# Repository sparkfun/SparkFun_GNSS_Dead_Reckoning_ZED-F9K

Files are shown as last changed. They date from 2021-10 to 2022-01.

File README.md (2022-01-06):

SparkFun GNSS-RTK Dead Reckoning Breakout - ZED-F9K (Qwiic)
========================================

SparkFun GNSS-RTK Dead Reckoning Breakout - ZED-F9K (Qwiic) (https://www.sparkfun.com/products/18719)

[*SparkFun GNSS-RTK Dead Reckoning Breakout - ZED-F9K (Qwiic) (GPS-18719)*](https://www.sparkfun.com/products/18719)

The SparkFun ZED-F9K GNSS Breakout is a high precision, sensor fusion geospatial board with equally impressive configuration options and takes advantage of u-blox's Automotive Dead Reckoning (ADR) technology. The ZED-F9K module provides a highly accurate and continuous position by fusing a 3D IMU sensor, wheel ticks, a vehicle dynamics model, correction data, and GNSS measurements. 

The ZED-F9K module is a 184-channel u-blox F9 engine GNSS receiver, meaning it can receive signals from the GPS, GLONASS, Galileo, and BeiDou constellations with ~0.2 meter accuracy! That's right, such accuracy can be achieved with an  RTK navigation solution when used with a correction source. Note that the ZED-F9K can only operate as a rover, so you will need to connect to a base station. The module supports concurrent reception of four GNSS systems. The combination of GNSS and integrated 3D sensor measurements on the ZED-F9K provide accurate, real-time positioning rates of up to 30Hz.

Compared to other GPS modules, this breakout maximizes position accuracy in dense cities or covered areas. Even under poor signal conditions, continuous positioning is provided in urban environments and is also available during complete signal loss (e.g. short tunnels and parking garages). The ZED-F9K is the ultimate solution for autonomous robotic applications that require accurate positioning under challenging conditions.

Additionally, this u-blox receiver supports I<sup>2</sup>C (u-blox calls this Display Data Channel) which makes it perfect for the Qwiic compatibility so we don't have to use up our precious UART ports. Utilizing our handy Qwiic system, no soldering is required to connect it to the rest of your system. However, we still have broken out 0.1"-spaced pins in case you prefer to use a breadboard.

The SparkFun ZED-F9K GPS Breakout is also equipped with an on-board rechargeable battery that provides power to the RTC on the ZED-F9K.  This reduces the time-to-first fix from a cold start (~26s) to a hot start (~2s). The battery will maintain RTC and GNSS orbit data without being connected to power for plenty of time. The breakout board has five communications ports, four of which are all active simultaneously: USB-C (which enumerates as a COM port), UART1 (with 3.3V TTL), UART2 for RTCM reception (with 3.3V TTL), I<sup>2</sup>C (via the one Qwiic connnector or broken out pins), and SPI. One SMA connector is included for a secure connection to an antenna.

U-blox based GPS products are configurable using the popular, but dense, Windows program called u-center. Plenty of different functions can be configured on the ZED-F9K: baud rates, update rates, geofencing, spoofing detection, external interrupts, SBAS/D-GPS, etc. All of this can be done within the [SparkFun Arduino Library](https://github.com/sparkfun/SparkFun_u-blox_GNSS_Arduino_Library)!

Repository Contents
-------------------

* **/Hardware** - Eagle design files (.brd, .sch)
* **/Production** - Production panel files (.brd)

Documentation
--------------
* **[Library](https://github.com/sparkfun/SparkFun_u-blox_GNSS_Arduino_Library)** - Arduino library
* **[Hookup Guide](https://learn.sparkfun.com/tutorials/2005)** - Basic hookup guide

Product Versions
----------------
* [GPS-18719](https://www.sparkfun.com/products/18719) - Initial release

Version History
---------------
* v1.0 - Initial Release 

License Information
-------------------

This product is _**open source**_! 

Please review the LICENSE.md file for license information. 

If you have any questions or concerns on licensing, please contact technical support on our [SparkFun forums](https://forum.sparkfun.com/viewforum.php?f=152).

Distributed as-is; no warranty is given.

- Your friends at SparkFun.

_<COLLABORATION CREDIT>_

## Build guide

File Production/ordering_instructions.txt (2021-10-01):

panel size, 101x186mm
PCB thickness, 1.6mm
number of layers, 2
soldermask color, Red
silkscreen color, White
oz copper, 1oz
finish, HASL lead free
stencils, top
pcs per panel, 6
min trace width, 0.2540mm / 0.0100in
min drill size, 0.3048mm / 0.0120in

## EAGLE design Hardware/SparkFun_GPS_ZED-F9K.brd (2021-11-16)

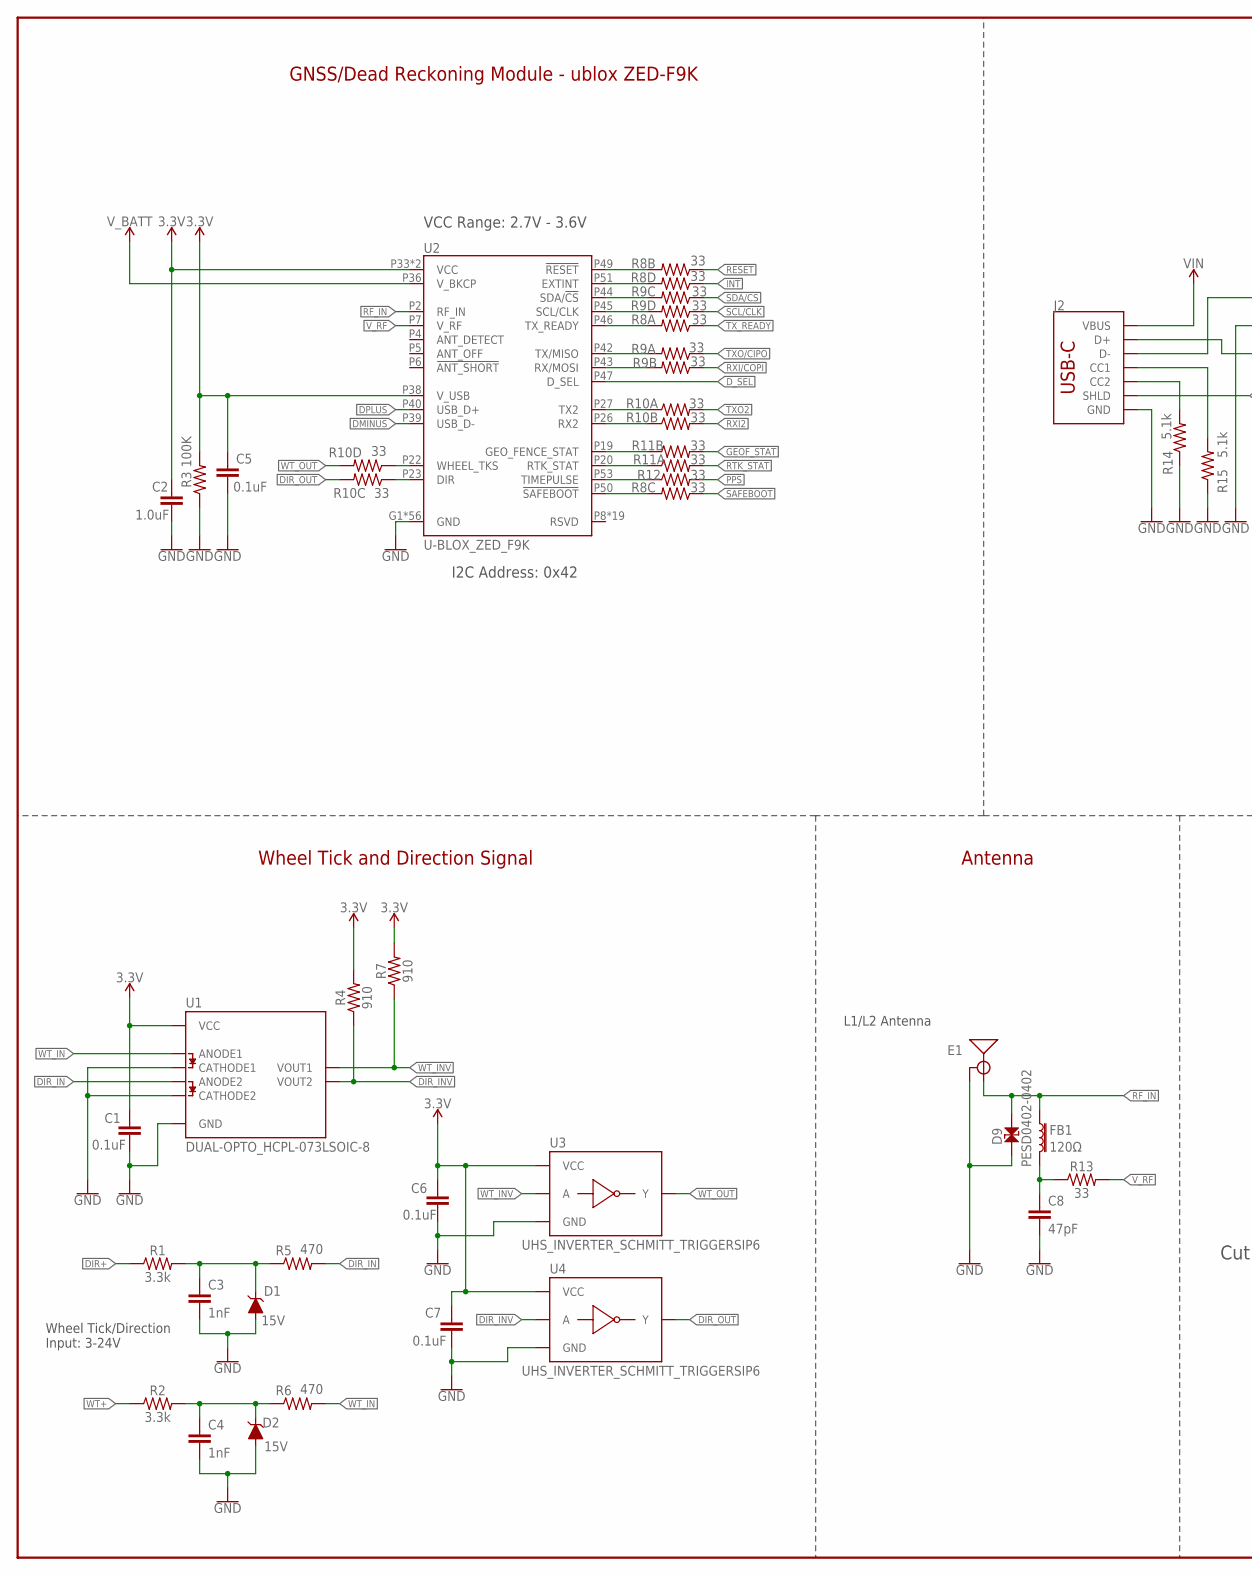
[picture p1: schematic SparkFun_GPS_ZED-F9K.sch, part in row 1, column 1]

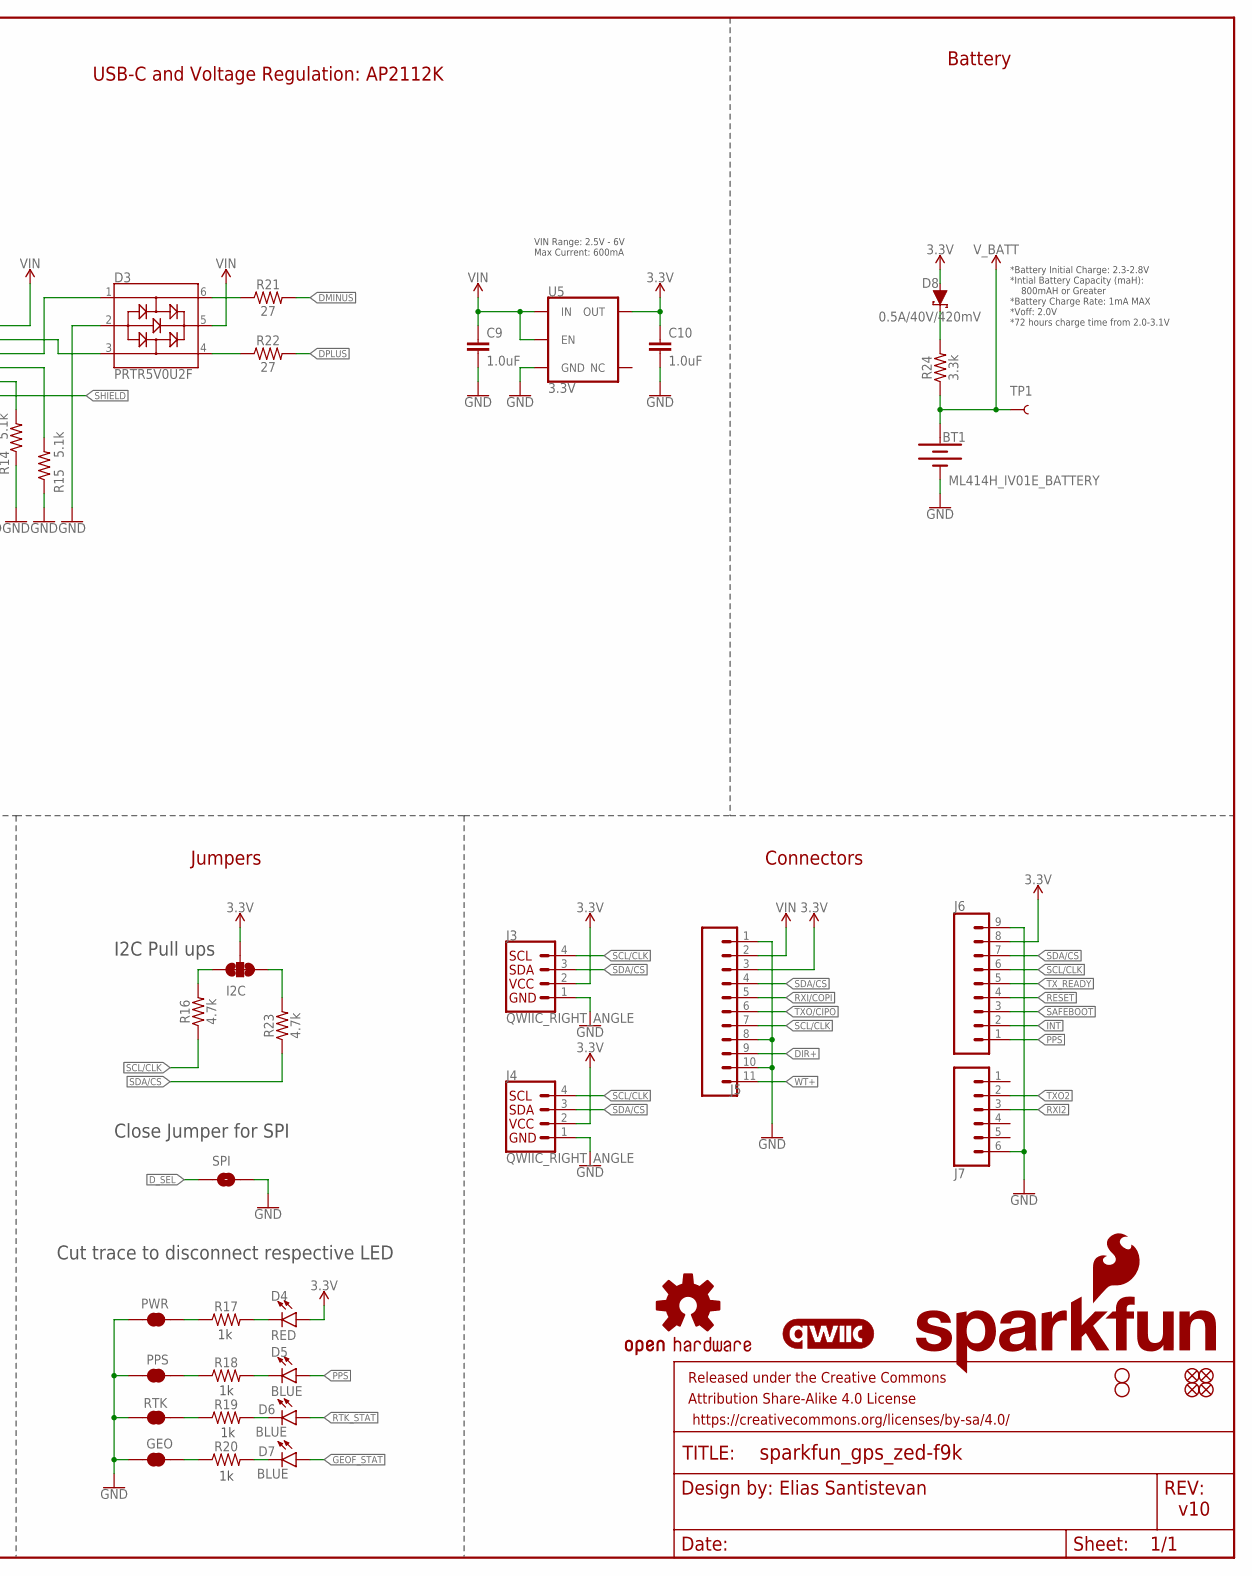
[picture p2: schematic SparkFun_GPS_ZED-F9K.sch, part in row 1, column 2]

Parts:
$1_25_$_2020-03-30_22-52-05: STAND-OFFTIGHT; STAND-OFF-TIGHT
BT1: ML414H_IV01E_BATTERY; ML414H_IV01E
C1, C5, C6, C7: 0.1uF; 0402-TIGHT
C2, C9, C10: 1.0uF; 0402-TIGHT
C3, C4: 1nF; 0402
C8: 47pF; 0402
D1, D2: 15V; SOT23-3
D3: PRTR5V0U2F; SOT886
D4: RED; LED-0603
D5, D6, D7: BLUE; LED-0603
D8: 0.5A/40V/420mV; SOD-323
D9: PESD0402-0402; 0402
E1: ANTENNA-SMA-GROUNDEDEDGE_SMA; SMA-EDGE
FB1: 120Ω; 0402
FD1, FD2, FD3, FD4: FIDUCIALUFIDUCIAL; FIDUCIAL-MICRO
FRAME1: FRAME-LEDGER; CREATIVE_COMMONS
GEO: JUMPER-SMT_2_NC_TRACE_SILK; SMT-JUMPER_2_NC_TRACE_SILK
H2: STAND-OFFTIGHT; STAND-OFF-TIGHT
I2C: JUMPER-SMT_3_2-NC_TRACE_SILK; SMT-JUMPER_3_2-NC_TRACE_SILK
J2: USB_C_2-LAYER_PADS; USB-C-16P-2LAYER-PADS
J3, J4: QWIIC_RIGHT_ANGLE; JST04_1MM_RA
J5: CONN_111X11_NO_SILK; 1X11_NO_SILK
J6: CONN_09NO_SILK; 1X09_NO_SILK
J7: CONN_06NO_SILK_NO_POP; 1X06_NO_SILK
LOGO1: OSHW-LOGOS; OSHW-LOGO-S
LOGO2: QWIIC_LOGO_4MM; QWIIC_4MM
LOGO3: SFE_LOGO_NAME_FLAME.2_INCH; SFE_LOGO_NAME_FLAME_.2
PPS: JUMPER-SMT_2_NC_TRACE_SILK; SMT-JUMPER_2_NC_TRACE_SILK
PWR: JUMPER-SMT_2_NC_TRACE_SILK; SMT-JUMPER_2_NC_TRACE_SILK
R1, R2, R24: 3.3k; 0603
R3: 100K; 0402
R4, R7: 910; 0603
R5, R6: 470; 0603
R8, R9, R10, R11: 33; 1206_RA
R12, R13: 33; 0603
R14, R15: 5.1k; 0402
R16, R23: 4.7k; 0402-TIGHT
R17, R18, R19, R20: 1KOHM-0402-1/16W-1%; 0402
R21, R22: 27; 0603
RTK: JUMPER-SMT_2_NC_TRACE_SILK; SMT-JUMPER_2_NC_TRACE_SILK
SPI: JUMPER-SMT_2_NO_SILK; SMT-JUMPER_2_NO_SILK
TP1: TEST-POINT3X5; PAD.03X.05
U1: DUAL-OPTO_HCPL-073LSOIC-8; SO08
U2: U-BLOX_ZED_F9K; UBLOX_ZED_F9K
U3, U4: UHS_INVERTER_SCHMITT_TRIGGERSIP6; SIP6
U5: 3.3V; SOT23-5

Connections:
3.3V: C1.1, C2.1, C5.1, C6.1, C7.1, C10.1, D4.A, D8.A, I2C.2, J3.2, J4.2, J5.3, J6.8, R3.2, R4.2, R7.2, U1.8 (VCC), U2.P33 (VCC), U2.P34 (VCC), U2.P38 (V_USB), U3.P6 (VCC), U4.P6 (VCC), U5.5 (OUT)
!RESET: J6.4, R8.P2 (1)
!SAFEBOOT: J6.3, R8.P3 (1)
DIR+: J5.9, R1.1
DIR_IN: R5.2, U1.4 (ANODE2)
DIR_INV: R4.1, U1.6 (VOUT2), U4.P2 (A)
DIR_OUT: R10.P6 (2), U4.P4 (Y)
DMINUS: R21.2, U2.P39 (USB_D-)
DPLUS: R22.2, U2.P40 (USB_D+)
D_SEL: SPI.1, U2.P47 (D_SEL)
GEOF_STAT: D7.A, R11.P7 (2)
GND: BT1.-, C1.2, C2.2, C3.2, C4.2, C5.2, C6.2, C7.2, C8.2, C9.2, C10.2, D1.1 (A), D2.1 (A), D3.2, D9.1, E1.GND@0 (GND), E1.GND@1 (GND), E1.GND@2 (GND), E1.GND@3 (GND), GEO.1, J2.GND, J2.GND2 (GND), J3.1, J4.1, J5.1, J5.8, J5.10, J6.9, J7.6, PPS.1, PWR.1, R3.1, R14.1, R15.1, RTK.1, SPI.2, U1.2 (CATHODE1), U1.3 (CATHODE2), U1.5 (GND), U2.G1 (GND), U2.G2 (GND), U2.G3 (GND), U2.G4 (GND), U2.G5 (GND), U2.G6 (GND), U2.G7 (GND), U2.G8 (GND), U2.G9 (GND), U2.G10 (GND), U2.G11 (GND), U2.G12 (GND), U2.G13 (GND), U2.G14 (GND), U2.G15 (GND), U2.G16 (GND), U2.G17 (GND), U2.G18 (GND), U2.G19 (GND), U2.G20 (GND), U2.G21 (GND), U2.G22 (GND), U2.G23 (GND), U2.G24 (GND), U2.G25 (GND), U2.G26 (GND), U2.G27 (GND), U2.G28 (GND), U2.G29 (GND), U2.G30 (GND), U2.G31 (GND), U2.G32 (GND), U2.G33 (GND), U2.G34 (GND), U2.G35 (GND), U2.G36 (GND), U2.G37 (GND), U2.G38 (GND), U2.G39 (GND), U2.G40 (GND), U2.G41 (GND), U2.G42 (GND), U2.G43 (GND), U2.G44 (GND), U2.G45 (GND), U2.G46 (GND), U2.G47 (GND), U2.G48 (GND), U2.P1 (GND), U2.P3 (GND), U2.P12 (GND), U2.P14 (GND), U2.P32 (GND), U2.P37 (GND), U2.P41 (GND), U2.P48 (GND), U3.P3 (GND), U4.P3 (GND), U5.2 (GND)
INT: J6.2, R8.P4 (1)
unnamed: I2C.1, R23.2
unnamed: D8.C, R24.2
unnamed: I2C.3, R16.2
unnamed: D4.C, R17.2
unnamed: C8.1, FB1.2, R13.1
unnamed: D3.3, J2.A6 (D+), J2.B6 (D+)
unnamed: D3.1, J2.A7 (D-), J2.B7 (D-)
unnamed: PWR.2, R17.1
unnamed: D3.6, R21.1
unnamed: D3.4, R22.1
unnamed: R8.P7 (2), U2.P49 (!RESET!)
unnamed: R8.P5 (2), U2.P51 (EXTINT)
unnamed: J2.B5 (CC2), R14.2
unnamed: J2.A5 (CC1), R15.2
unnamed: R9.P6 (2), U2.P44 (SDA/!CS!)
unnamed: R9.P5 (2), U2.P45 (SCL/CLK)
unnamed: R8.P8 (2), U2.P46 (TX_READY)
unnamed: R9.P8 (2), U2.P42 (TX/MISO)
unnamed: R9.P7 (2), U2.P43 (RX/MOSI)
unnamed: R10.P1 (1), U2.P27 (TX2)
unnamed: R19.1, RTK.2
unnamed: PPS.2, R18.1
unnamed: D5.C, R18.2
unnamed: D6.C, R19.2
unnamed: R10.P2 (1), U2.P26 (RX2)
unnamed: R11.P2 (1), U2.P19 (GEO_FENCE_STAT)
unnamed: R11.P1 (1), U2.P20 (RTK_STAT)
unnamed: R12.1, U2.P53 (TIMEPULSE)
unnamed: R8.P6 (2), U2.P50 (!SAFEBOOT!)
unnamed: R10.P4 (1), U2.P22 (WHEEL_TKS)
unnamed: R10.P3 (1), U2.P23 (DIR)
unnamed: GEO.2, R20.1
unnamed: D7.C, R20.2
unnamed: C4.1, D2.3 (C), R2.2, R6.1
unnamed: C3.1, D1.3 (C), R1.2, R5.1
PPS: D5.A, J6.1, R12.2
RF_IN: D9.2, E1.SIG (SIGNAL), FB1.1, U2.P2 (RF_IN)
RTK_STAT: D6.A, R11.P8 (2)
RXI2: J7.3, R10.P7 (2)
RXI/COPI: J5.5, R9.P2 (1)
SCL/CLK: J3.4, J4.4, J5.7, J6.6, R9.P4 (1), R16.1
SDA/!CS: J3.3, J4.3, J5.4, J6.7, R9.P3 (1), R23.1
SHIELD: J2.SHLD1 (SHLD), J2.SHLD2 (SHLD), J2.SHLD3 (SHLD), J2.SHLD4 (SHLD)
TXO2: J7.2, R10.P8 (2)
TXO/CIPO: J5.6, R9.P1 (1)
TX_READY: J6.5, R8.P1 (1)
VIN: C9.1, D3.5, J2.VBUS1 (VBUS), J2.VBUS2 (VBUS), J5.2, U5.1 (IN), U5.3 (EN)
V_BATT: BT1.+, R24.1, TP1.1, U2.P36 (V_BKCP)
V_RF: R13.2, U2.P7 (V_RF)
WT+: J5.11, R2.1
WT_IN: R6.2, U1.1 (ANODE1)
WT_INV: R7.1, U1.7 (VOUT1), U3.P2 (A)
WT_OUT: R10.P5 (2), U3.P4 (Y)

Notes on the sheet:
v10
Elias Santistevan
GNSS/Dead Reckoning Module - ublox ZED-F9K
Battery
Connectors
Jumpers
Close Jumper for SPI
I2C Pull ups
Cut trace to disconnect respective LED
Antenna
*Battery Initial Charge: 2.3-2.8V *Intial Battery Capacity (maH): 800mAH or Greater *Battery Charge Rate: 1mA MAX *Voff: 2.0V *72 hours charge time from 2.0-3.1V
VIN Range: 2.5V - 6V Max Current: 600mA
USB-C and Voltage Regulation: AP2112K
VCC Range: 2.7V - 3.6V
I2C Address: 0x42
Wheel Tick and Direction Signal
Wheel Tick/Direction Input: 3-24V
L1/L2 Antenna

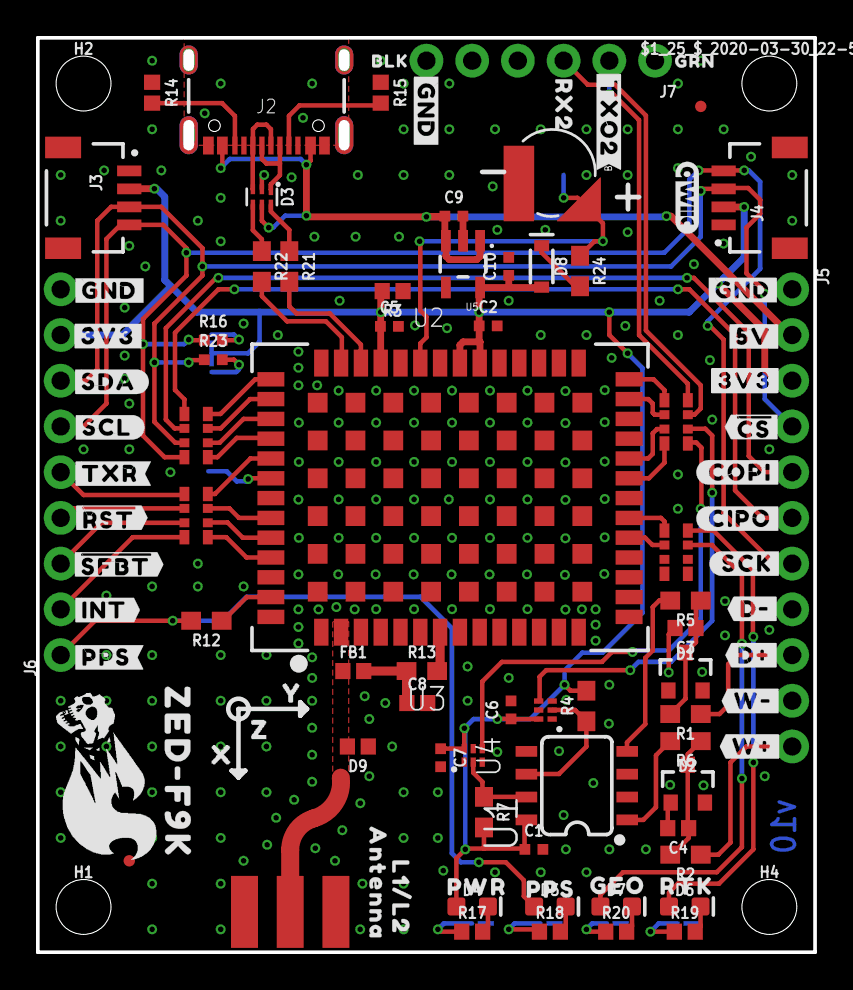
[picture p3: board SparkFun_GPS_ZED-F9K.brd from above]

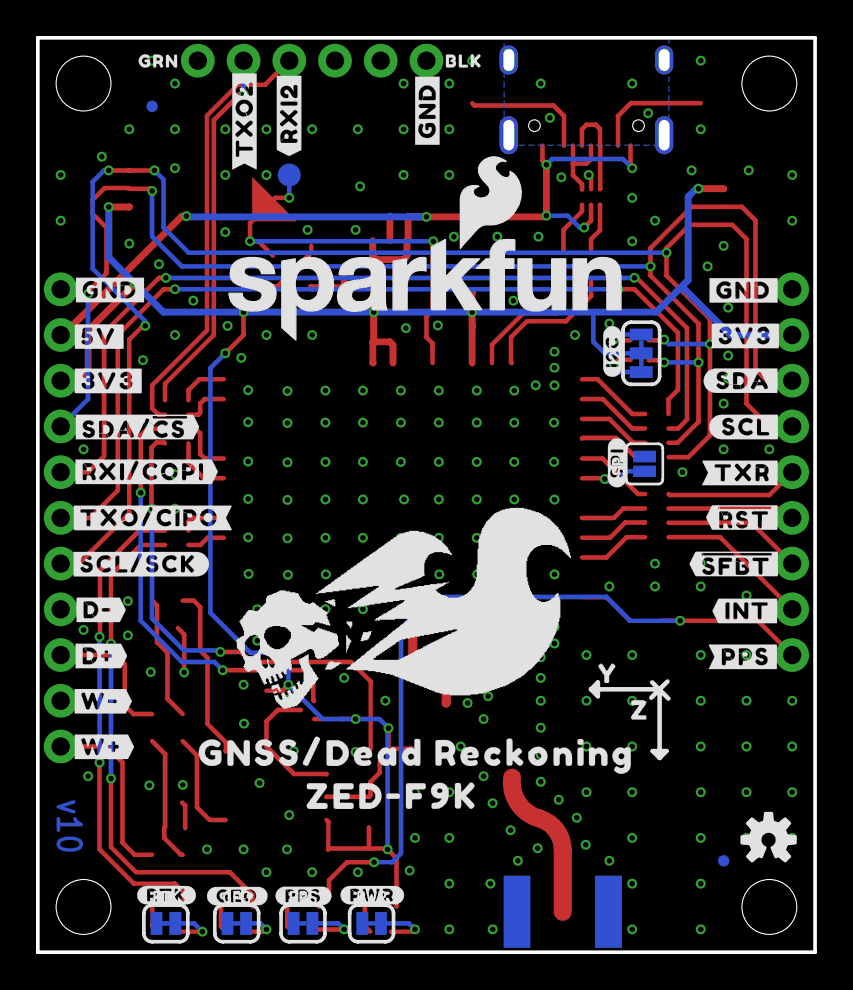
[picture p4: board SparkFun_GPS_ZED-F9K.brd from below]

Board: 2 copper layers, 43.2 x 50.8 mm, 149 parts (47 on the bottom side), 66 nets.

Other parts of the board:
H1, H4: STAND-OFFTIGHT; STAND-OFF-TIGHT
U$1: PWR22
U$2: PPS21
U$3: GEO23
U$4: RTK24
U$5: #W##16
U$6: #W##15
U$7, U$14, U$22, U$37, U$55: #3V3#6
U$8: #D##13
U$9: #D##14
U$10: #SCK#12
U$11: #CIPO#10
U$12: #COPI#9
U$13: ##CS##11
U$15, U$24: #5V#1
U$16, U$17, U$25, U$36, U$44, U$58: #GND#0
U$18: #TXO2#20
U$19, U$20: DEAD#RECKONING#GPS#BOARD#SILK#FINAL#JPG
U$21: RX224
U$23: BLK225
U$26: GRN226
U$27: #SDA##CS##10
U$28: #RXI#COPI#8
U$30: #SCL#SCK#12
U$31: #D##6
U$32: X1
U$33: #D##7
U$34: #W##4
U$35: #W##5
U$38: #SDA#6
U$39: #SCL#7
U$40: #TXR#3
U$41: ##RST##16
U$42: ##SFBT##17
U$43: #INT#8
U$45: #PPS#0
U$46: #RTK#25
U$47: #GEO#24
U$48: #PPS#21
U$49: L1#L2229
U$50, U$52: Y2
U$51: #PWR#23
U$53: #SPI#22
U$54: #I2C#23
U$56: #SDA#12
U$57, U$63: Z0
U$59: #RXI2#227
U$60: #TXO2#1
U$61: BLK227
U$62: ANTENNA229
U$64: GRN228
U$65: GNSS#DEAD_RECKONING230
U$66: #SCL#13
U$67: #TXR#19
U$68: ##RST##17
U$69: ##SFBT##18
U$70: #INT#14
U$71: #PPS#20
U$72, U$73: ZED#F9K230
U$74: #TXO#CIPO#9

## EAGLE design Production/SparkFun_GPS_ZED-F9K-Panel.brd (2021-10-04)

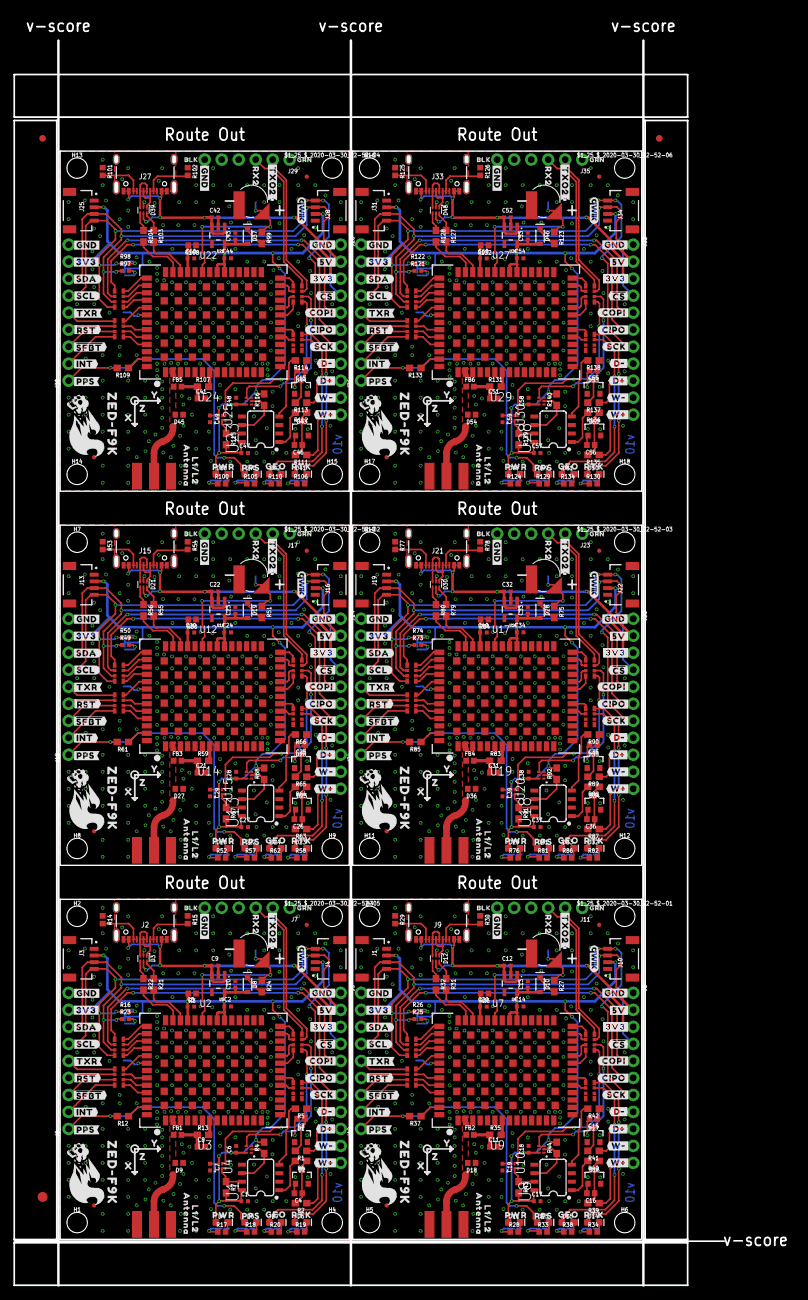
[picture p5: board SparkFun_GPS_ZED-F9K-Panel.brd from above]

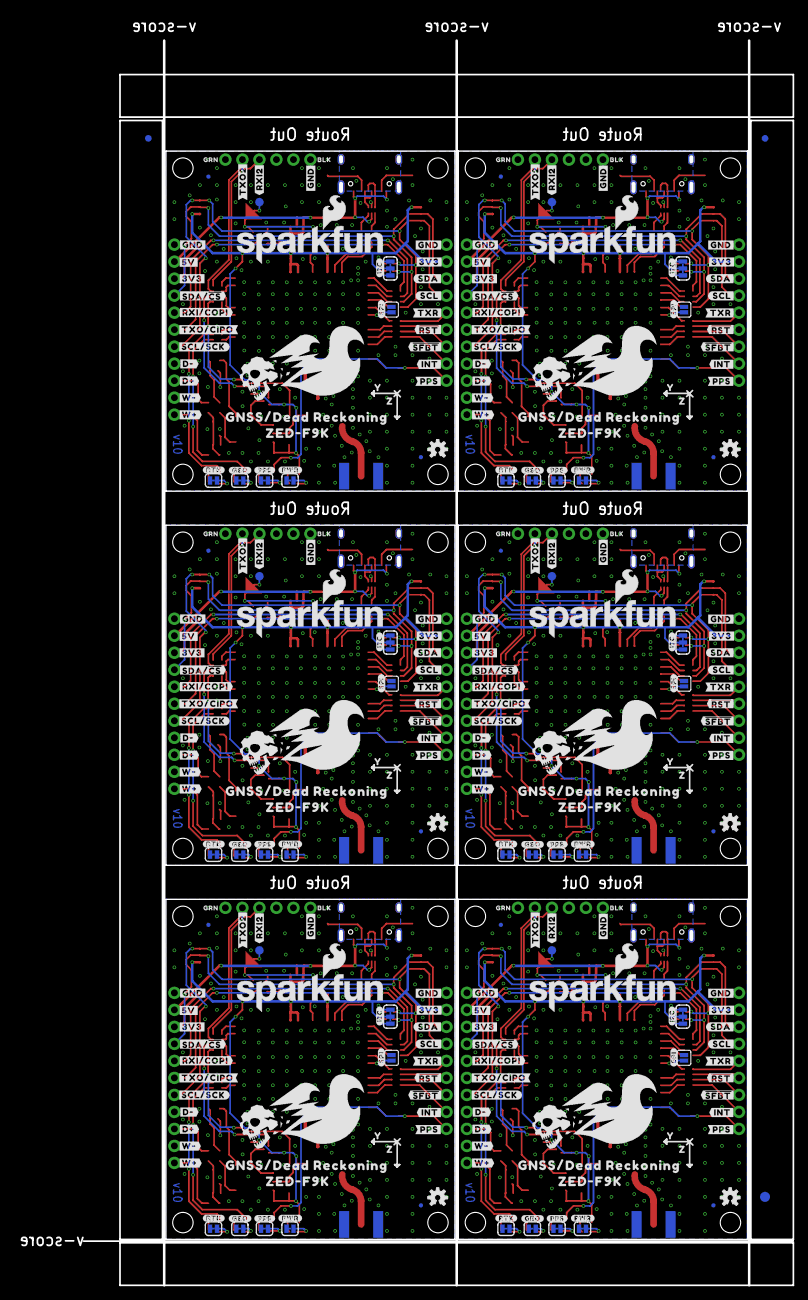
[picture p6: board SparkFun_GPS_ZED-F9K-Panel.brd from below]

Board: 2 copper layers, 106.0 x 185.9 mm, 894 parts (285 on the bottom side), 396 nets.

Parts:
$1_25_$_2020-03-30_22-52-01, $1_25_$_2020-03-30_22-52-02, $1_25_$_2020-03-30_22-52-03, $1_25_$_2020-03-30_22-52-04, $1_25_$_2020-03-30_22-52-05, $1_25_$_2020-03-30_22-52-06: STAND-OFFTIGHT; STAND-OFF-TIGHT
BT1, BT2, BT3, BT4, BT5, BT6: ML414H_IV01E_BATTERY; ML414H_IV01E
C1, C5, C6, C7, C17, C18, C19, C20, C27, C28, C29, C30, C37, C38, C39, C40, C47, C48, C49, C50, C57, C58, C59, C60: 0.1uF; 0402-TIGHT
C2, C9, C10, C12, C13, C14, C22, C23, C24, C32, C33, C34, C42, C43, C44, C52, C53, C54: 1.0uF; 0402-TIGHT
C3, C4, C15, C16, C25, C26, C35, C36, C45, C46, C55, C56: 1nF; 0402
C8, C11, C21, C31, C41, C51: 47pF; 0402
D1, D2, D16, D17, D25, D26, D34, D35, D43, D44, D52, D53: 15V; SOT23-3
D3, D12, D21, D30, D39, D48: PRTR5V0U2F; SOT886
D4, D11, D20, D29, D38, D47: RED; LED-0603
D5, D6, D7, D13, D14, D15, D22, D23, D24, D31, D32, D33, D40, D41, D42, D49, D50, D51: BLUE; LED-0603
D8, D10, D19, D28, D37, D46: 0.5A/40V/420mV; SOD-323
D9, D18, D27, D36, D45, D54: PESD0402; 0402
E1, E2, E3, E4, E5, E6: ANTENNA-SMA-GROUNDEDEDGE_SMA; SMA-EDGE
E$1, E$2, E$3, E$4: FIDUCIAL-1X2
E$5, E$6: FIDUCIAL-1.5X3
FB1, FB2, FB3, FB4, FB5, FB6: 120Ω; 0402
FD1, FD2, FD3, FD4, FD5, FD6, FD7, FD8, FD9, FD10, FD11, FD12, FD13, FD14, FD15, FD16, FD17, FD18, FD19, FD20, FD21, FD22, FD23, FD24: FIDUCIALUFIDUCIAL; FIDUCIAL-MICRO
GEO, GEO1, GEO2, GEO3, GEO4, GEO5: JUMPER-SMT_2_NC_TRACE_SILK; SMT-JUMPER_2_NC_TRACE_SILK
H1, H2, H3, H4, H5, H6, H7, H8, H9, H10, H11, H12, H13, H14, H15, H16, H17, H18: STAND-OFFTIGHT; STAND-OFF-TIGHT
I2C, I2C1, I2C2, I2C3, I2C4, I2C5: JUMPER-SMT_3_2-NC_TRACE_SILK; SMT-JUMPER_3_2-NC_TRACE_SILK
J1, J3, J4, J10, J13, J16, J19, J22, J25, J28, J31, J34: QWIIC_RIGHT_ANGLE; JST04_1MM_RA
J2, J9, J15, J21, J27, J33: USB-C-16P-2LAYER-PADS
J5, J8, J14, J20, J26, J32: 1X11_NO_SILK
J6, J12, J18, J24, J30, J36: 1X09_NO_SILK
J7, J11, J17, J23, J29, J35: 1X06_NO_SILK
LOGO1, LOGO6, LOGO9, LOGO12, LOGO15, LOGO18: OSHW-LOGOS; OSHW-LOGO-S
LOGO2, LOGO5, LOGO8, LOGO11, LOGO14, LOGO17: QWIIC_LOGO_4MM; QWIIC_4MM
LOGO3, LOGO4, LOGO7, LOGO10, LOGO13, LOGO16: SFE_LOGO_NAME_FLAME.2_INCH; SFE_LOGO_NAME_FLAME_.2
PPS, PPS1, PPS2, PPS3, PPS4, PPS5: JUMPER-SMT_2_NC_TRACE_SILK; SMT-JUMPER_2_NC_TRACE_SILK
PWR, PWR1, PWR2, PWR3, PWR4, PWR5: JUMPER-SMT_2_NC_TRACE_SILK; SMT-JUMPER_2_NC_TRACE_SILK
R1, R2, R24, R27, R39, R41, R51, R63, R65, R75, R87, R89, R99, R111, R113, R123, R135, R137: 3.3k; 0603
R3, R36, R60, R84, R108, R132: 100K; 0402
R4, R7, R43, R44, R67, R68, R91, R92, R115, R116, R139, R140: 910; 0603
R5, R6, R40, R42, R64, R66, R88, R90, R112, R114, R136, R138: 470; 0603
R8, R9, R10, R11, R45, R46, R47, R48, R69, R70, R71, R72, R93, R94, R95, R96, R117, R118, R119, R120, R141, R142, R143, R144: 33; 1206_RA
R12, R13, R35, R37, R59, R61, R83, R85, R107, R109, R131, R133: 33; 0603
R14, R15, R29, R30, R53, R54, R77, R78, R101, R102, R125, R126: 5.1k; 0402
R16, R23, R25, R26, R49, R50, R73, R74, R97, R98, R121, R122: 4.7k; 0402-TIGHT
R17, R18, R19, R20, R28, R33, R34, R38, R52, R57, R58, R62, R76, R81, R82, R86, R100, R105, R106, R110, R124, R129, R130, R134: 1KOHM-0402-1/16W-1%; 0402
R21, R22, R31, R32, R55, R56, R79, R80, R103, R104, R127, R128: 27; 0603
RTK, RTK1, RTK2, RTK3, RTK4, RTK5: JUMPER-SMT_2_NC_TRACE_SILK; SMT-JUMPER_2_NC_TRACE_SILK
SPI, SPI1, SPI2, SPI3, SPI4, SPI5: JUMPER-SMT_2_NO_SILK; SMT-JUMPER_2_NO_SILK
TP1, TP2, TP3, TP4, TP5, TP6: TEST-POINT3X5; PAD.03X.05
U1, U8, U13, U18, U23, U28: DUAL-OPTO_HCPL-073LSOIC-8; SO08
U2, U7, U12, U17, U22, U27: U-BLOX_ZED_F9K; UBLOX_ZED_F9K
U3, U4, U9, U10, U14, U15, U19, U20, U24, U25, U29, U30: UHS_INVERTER_SCHMITT_TRIGGERSIP6; SIP6
U5, U6, U11, U16, U21, U26: 3.3V; SOT23-5
U$1, U$81, U$154, U$227, U$300, U$373: PWR22
U$2, U$82, U$155, U$228, U$301, U$374: PPS21
U$3, U$83, U$156, U$229, U$302, U$375: GEO23
U$4, U$84, U$157, U$230, U$303, U$376: RTK24
U$5, U$85, U$158, U$231, U$304, U$377: #W##16
U$6, U$86, U$159, U$232, U$305, U$378: #W##15
U$7, U$14, U$22, U$37, U$55, U$92, U$101, U$109, U$110, U$121, U$165, U$174, U$182, U$183, U$194, U$238, U$247, U$255, U$256, U$267, U$311, U$320, U$328, U$329, U$340, U$384, U$393, U$401, U$402, U$413: #3V3#6
U$8, U$87, U$160, U$233, U$306, U$379: #D##13
U$9, U$88, U$161, U$234, U$307, U$380: #D##14
U$10, U$89, U$162, U$235, U$308, U$381: #SCK#12
U$11, U$90, U$163, U$236, U$309, U$382: #CIPO#10
U$12, U$91, U$164, U$237, U$310, U$383: #COPI#9
U$13, U$108, U$181, U$254, U$327, U$400: ##CS##11
U$15, U$24, U$93, U$111, U$166, U$184, U$239, U$257, U$312, U$330, U$385, U$403: #5V#1
U$16, U$17, U$25, U$36, U$44, U$58, U$94, U$95, U$100, U$112, U$120, U$137, U$167, U$168, U$173, U$185, U$193, U$210, U$240, U$241, U$246, U$258, U$266, U$283, U$313, U$314, U$319, U$331, U$339, U$356, U$386, U$387, U$392, U$404, U$412, U$429: #GND#0
U$18, U$96, U$169, U$242, U$315, U$388: #TXO2#20
U$19, U$20, U$29, U$75, U$147, U$148, U$220, U$221, U$293, U$294, U$366, U$367: DEAD#RECKONING#GPS#BOARD#SILK#FINAL#JPG
U$21, U$97, U$170, U$243, U$316, U$389: RX224
U$23, U$98, U$171, U$244, U$317, U$390: BLK225
U$26, U$99, U$172, U$245, U$318, U$391: GRN226
U$27, U$113, U$186, U$259, U$332, U$405: #SDA##CS##10
U$28, U$114, U$187, U$260, U$333, U$406: #RXI#COPI#8
U$30, U$115, U$188, U$261, U$334, U$407: #SCL#SCK#12
U$31, U$116, U$189, U$262, U$335, U$408: #D##6
U$32, U$76, U$149, U$222, U$295, U$368: X1
U$33, U$117, U$190, U$263, U$336, U$409: #D##7
U$34, U$118, U$191, U$264, U$337, U$410: #W##4
U$35, U$119, U$192, U$265, U$338, U$411: #W##5
U$38, U$122, U$195, U$268, U$341, U$414: #SDA#6
U$39, U$123, U$196, U$269, U$342, U$415: #SCL#7
U$40, U$124, U$197, U$270, U$343, U$416: #TXR#3
U$41, U$125, U$198, U$271, U$344, U$417: ##RST##16
U$42, U$126, U$199, U$272, U$345, U$418: ##SFBT##17
U$43, U$127, U$200, U$273, U$346, U$419: #INT#8
U$45, U$128, U$201, U$274, U$347, U$420: #PPS#0
U$46, U$129, U$202, U$275, U$348, U$421: #RTK#25
U$47, U$130, U$203, U$276, U$349, U$422: #GEO#24
U$48, U$131, U$204, U$277, U$350, U$423: #PPS#21
U$49, U$142, U$215, U$288, U$361, U$434: L1#L2229
U$50, U$52, U$77, U$78, U$150, U$151, U$223, U$224, U$296, U$297, U$369, U$370: Y2
U$51, U$132, U$205, U$278, U$351, U$424: #PWR#23
U$53, U$133, U$206, U$279, U$352, U$425: #SPI#22
U$54, U$134, U$207, U$280, U$353, U$426: #I2C#23
U$56, U$102, U$175, U$248, U$321, U$394: #SDA#12
U$57, U$63, U$79, U$80, U$152, U$153, U$225, U$226, U$298, U$299, U$371, U$372: Z0
U$59, U$135, U$208, U$281, U$354, U$427: #RXI2#227
U$60, U$136, U$209, U$282, U$355, U$428: #TXO2#1
U$61, U$138, U$211, U$284, U$357, U$430: BLK227
U$62, U$143, U$216, U$289, U$362, U$435: ANTENNA229
U$64, U$139, U$212, U$285, U$358, U$431: GRN228
U$65, U$140, U$213, U$286, U$359, U$432: GNSS#DEAD_RECKONING230
U$66, U$103, U$176, U$249, U$322, U$395: #SCL#13
U$67, U$104, U$177, U$250, U$323, U$396: #TXR#19
U$68, U$105, U$178, U$251, U$324, U$397: ##RST##17
U$69, U$106, U$179, U$252, U$325, U$398: ##SFBT##18
U$70, U$107, U$180, U$253, U$326, U$399: #INT#14
U$71, U$145, U$218, U$291, U$364, U$437: #PPS#20
U$72, U$73, U$141, U$144, U$214, U$217, U$287, U$290, U$360, U$363, U$433, U$436: ZED#F9K230
U$74, U$146, U$219, U$292, U$365, U$438: #TXO#CIPO#9

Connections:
3.3V: C1.1, C2.1, C5.1, C6.1, C7.1, C10.1, D4.A, D8.A, I2C.2, J3.2, J4.2, J5.3, J6.8, R3.2, R4.2, R7.2, U1.8, U2.P33, U2.P34, U2.P38, U3.P6, U4.P6, U5.5
3.3V1: C13.1, C14.1, C17.1, C18.1, C19.1, C20.1, D10.A, D11.A, I2C1.2, J1.2, J8.3, J10.2, J12.8, R36.2, R43.2, R44.2, U6.5, U7.P33, U7.P34, U7.P38, U8.8, U9.P6, U10.P6
3.3V2: C23.1, C24.1, C27.1, C28.1, C29.1, C30.1, D19.A, D20.A, I2C2.2, J13.2, J14.3, J16.2, J18.8, R60.2, R67.2, R68.2, U11.5, U12.P33, U12.P34, U12.P38, U13.8, U14.P6, U15.P6
3.3V3: C33.1, C34.1, C37.1, C38.1, C39.1, C40.1, D28.A, D29.A, I2C3.2, J19.2, J20.3, J22.2, J24.8, R84.2, R91.2, R92.2, U16.5, U17.P33, U17.P34, U17.P38, U18.8, U19.P6, U20.P6
3.3V4: C43.1, C44.1, C47.1, C48.1, C49.1, C50.1, D37.A, D38.A, I2C4.2, J25.2, J26.3, J28.2, J30.8, R108.2, R115.2, R116.2, U21.5, U22.P33, U22.P34, U22.P38, U23.8, U24.P6, U25.P6
3.3V5: C53.1, C54.1, C57.1, C58.1, C59.1, C60.1, D46.A, D47.A, I2C5.2, J31.2, J32.3, J34.2, J36.8, R132.2, R139.2, R140.2, U26.5, U27.P33, U27.P34, U27.P38, U28.8, U29.P6, U30.P6
!RESET: J6.4, R8.P2
!RESET1: J12.4, R46.P2
!RESET2: J18.4, R70.P2
!RESET3: J24.4, R94.P2
!RESET4: J30.4, R118.P2
!RESET5: J36.4, R142.P2
!SAFEBOOT: J6.3, R8.P3
!SAFEBOOT1: J12.3, R46.P3
!SAFEBOOT2: J18.3, R70.P3
!SAFEBOOT3: J24.3, R94.P3
!SAFEBOOT4: J30.3, R118.P3
!SAFEBOOT5: J36.3, R142.P3
DIR+: J5.9, R1.1
DIR+1: J8.9, R41.1
DIR+2: J14.9, R65.1
DIR+3: J20.9, R89.1
DIR+4: J26.9, R113.1
DIR+5: J32.9, R137.1
DIR_IN: R5.2, U1.4
DIR_IN1: R42.2, U8.4
DIR_IN2: R66.2, U13.4
DIR_IN3: R90.2, U18.4
DIR_IN4: R114.2, U23.4
DIR_IN5: R138.2, U28.4
DIR_INV: R4.1, U1.6, U4.P2
DIR_INV1: R44.1, U8.6, U10.P2
DIR_INV2: R68.1, U13.6, U15.P2
DIR_INV3: R92.1, U18.6, U20.P2
DIR_INV4: R116.1, U23.6, U25.P2
DIR_INV5: R140.1, U28.6, U30.P2
DIR_OUT: R10.P6, U4.P4
DIR_OUT1: R47.P6, U10.P4
DIR_OUT2: R71.P6, U15.P4
DIR_OUT3: R95.P6, U20.P4
DIR_OUT4: R119.P6, U25.P4
DIR_OUT5: R143.P6, U30.P4
DMINUS: R21.2, U2.P39
DMINUS1: R31.2, U7.P39
DMINUS2: R55.2, U12.P39
DMINUS3: R79.2, U17.P39
DMINUS4: R103.2, U22.P39
DMINUS5: R127.2, U27.P39
DPLUS: R22.2, U2.P40
DPLUS1: R32.2, U7.P40
DPLUS2: R56.2, U12.P40
DPLUS3: R80.2, U17.P40
DPLUS4: R104.2, U22.P40
DPLUS5: R128.2, U27.P40
D_SEL: SPI.1, U2.P47
D_SEL1: SPI1.1, U7.P47
D_SEL2: SPI2.1, U12.P47
D_SEL3: SPI3.1, U17.P47
D_SEL4: SPI4.1, U22.P47
D_SEL5: SPI5.1, U27.P47
GEOF_STAT: D7.A, R11.P7
GEOF_STAT1: D15.A, R48.P7
GEOF_STAT2: D24.A, R72.P7
GEOF_STAT3: D33.A, R96.P7
GEOF_STAT4: D42.A, R120.P7
GEOF_STAT5: D51.A, R144.P7
GND: BT1.-, C1.2, C2.2, C3.2, C4.2, C5.2, C6.2, C7.2, C8.2, C9.2, C10.2, D1.1, D2.1, D3.2, D9.1, E1.GND@0, E1.GND@1, E1.GND@2, E1.GND@3, GEO.1, J2.GND, J2.GND2, J3.1, J4.1, J5.1, J5.8, J5.10, J6.9, J7.6, PPS.1, PWR.1, R3.1, R14.1, R15.1, RTK.1, SPI.2, U1.2, U1.3, U1.5, U2.G1, U2.G2, U2.G3, U2.G4, U2.G5, U2.G6, U2.G7, U2.G8, U2.G9, U2.G10, U2.G11, U2.G12, U2.G13, U2.G14, U2.G15, U2.G16, U2.G17, U2.G18, U2.G19, U2.G20, U2.G21, U2.G22, U2.G23, U2.G24, U2.G25, U2.G26, U2.G27, U2.G28, U2.G29, U2.G30, U2.G31, U2.G32, U2.G33, U2.G34, U2.G35, U2.G36, U2.G37, U2.G38, U2.G39, U2.G40, U2.G41, U2.G42, U2.G43, U2.G44, U2.G45, U2.G46, U2.G47, U2.G48, U2.P1, U2.P3, U2.P12, U2.P14, U2.P32, U2.P37, U2.P41, U2.P48, U3.P3, U4.P3, U5.2
GND1: BT2.-, C11.2, C12.2, C13.2, C14.2, C15.2, C16.2, C17.2, C18.2, C19.2, C20.2, D12.2, D16.1, D17.1, D18.1, E2.GND@0, E2.GND@1, E2.GND@2, E2.GND@3, GEO1.1, J1.1, J8.1, J8.8, J8.10, J9.GND, J9.GND2, J10.1, J11.6, J12.9, PPS1.1, PWR1.1, R29.1, R30.1, R36.1, RTK1.1, SPI1.2, U6.2, U7.G1, U7.G2, U7.G3, U7.G4, U7.G5, U7.G6, U7.G7, U7.G8, U7.G9, U7.G10, U7.G11, U7.G12, U7.G13, U7.G14, U7.G15, U7.G16, U7.G17, U7.G18, U7.G19, U7.G20, U7.G21, U7.G22, U7.G23, U7.G24, U7.G25, U7.G26, U7.G27, U7.G28, U7.G29, U7.G30, U7.G31, U7.G32, U7.G33, U7.G34, U7.G35, U7.G36, U7.G37, U7.G38, U7.G39, U7.G40, U7.G41, U7.G42, U7.G43, U7.G44, U7.G45, U7.G46, U7.G47, U7.G48, U7.P1, U7.P3, U7.P12, U7.P14, U7.P32, U7.P37, U7.P41, U7.P48, U8.2, U8.3, U8.5, U9.P3, U10.P3
GND2: BT3.-, C21.2, C22.2, C23.2, C24.2, C25.2, C26.2, C27.2, C28.2, C29.2, C30.2, D21.2, D25.1, D26.1, D27.1, E3.GND@0, E3.GND@1, E3.GND@2, E3.GND@3, GEO2.1, J13.1, J14.1, J14.8, J14.10, J15.GND, J15.GND2, J16.1, J17.6, J18.9, PPS2.1, PWR2.1, R53.1, R54.1, R60.1, RTK2.1, SPI2.2, U11.2, U12.G1, U12.G2, U12.G3, U12.G4, U12.G5, U12.G6, U12.G7, U12.G8, U12.G9, U12.G10, U12.G11, U12.G12, U12.G13, U12.G14, U12.G15, U12.G16, U12.G17, U12.G18, U12.G19, U12.G20, U12.G21, U12.G22, U12.G23, U12.G24, U12.G25, U12.G26, U12.G27, U12.G28, U12.G29, U12.G30, U12.G31, U12.G32, U12.G33, U12.G34, U12.G35, U12.G36, U12.G37, U12.G38, U12.G39, U12.G40, U12.G41, U12.G42, U12.G43, U12.G44, U12.G45, U12.G46, U12.G47, U12.G48, U12.P1, U12.P3, U12.P12, U12.P14, U12.P32, U12.P37, U12.P41, U12.P48, U13.2, U13.3, U13.5, U14.P3, U15.P3
GND3: BT4.-, C31.2, C32.2, C33.2, C34.2, C35.2, C36.2, C37.2, C38.2, C39.2, C40.2, D30.2, D34.1, D35.1, D36.1, E4.GND@0, E4.GND@1, E4.GND@2, E4.GND@3, GEO3.1, J19.1, J20.1, J20.8, J20.10, J21.GND, J21.GND2, J22.1, J23.6, J24.9, PPS3.1, PWR3.1, R77.1, R78.1, R84.1, RTK3.1, SPI3.2, U16.2, U17.G1, U17.G2, U17.G3, U17.G4, U17.G5, U17.G6, U17.G7, U17.G8, U17.G9, U17.G10, U17.G11, U17.G12, U17.G13, U17.G14, U17.G15, U17.G16, U17.G17, U17.G18, U17.G19, U17.G20, U17.G21, U17.G22, U17.G23, U17.G24, U17.G25, U17.G26, U17.G27, U17.G28, U17.G29, U17.G30, U17.G31, U17.G32, U17.G33, U17.G34, U17.G35, U17.G36, U17.G37, U17.G38, U17.G39, U17.G40, U17.G41, U17.G42, U17.G43, U17.G44, U17.G45, U17.G46, U17.G47, U17.G48, U17.P1, U17.P3, U17.P12, U17.P14, U17.P32, U17.P37, U17.P41, U17.P48, U18.2, U18.3, U18.5, U19.P3, U20.P3
GND4: BT5.-, C41.2, C42.2, C43.2, C44.2, C45.2, C46.2, C47.2, C48.2, C49.2, C50.2, D39.2, D43.1, D44.1, D45.1, E5.GND@0, E5.GND@1, E5.GND@2, E5.GND@3, GEO4.1, J25.1, J26.1, J26.8, J26.10, J27.GND, J27.GND2, J28.1, J29.6, J30.9, PPS4.1, PWR4.1, R101.1, R102.1, R108.1, RTK4.1, SPI4.2, U21.2, U22.G1, U22.G2, U22.G3, U22.G4, U22.G5, U22.G6, U22.G7, U22.G8, U22.G9, U22.G10, U22.G11, U22.G12, U22.G13, U22.G14, U22.G15, U22.G16, U22.G17, U22.G18, U22.G19, U22.G20, U22.G21, U22.G22, U22.G23, U22.G24, U22.G25, U22.G26, U22.G27, U22.G28, U22.G29, U22.G30, U22.G31, U22.G32, U22.G33, U22.G34, U22.G35, U22.G36, U22.G37, U22.G38, U22.G39, U22.G40, U22.G41, U22.G42, U22.G43, U22.G44, U22.G45, U22.G46, U22.G47, U22.G48, U22.P1, U22.P3, U22.P12, U22.P14, U22.P32, U22.P37, U22.P41, U22.P48, U23.2, U23.3, U23.5, U24.P3, U25.P3
GND5: BT6.-, C51.2, C52.2, C53.2, C54.2, C55.2, C56.2, C57.2, C58.2, C59.2, C60.2, D48.2, D52.1, D53.1, D54.1, E6.GND@0, E6.GND@1, E6.GND@2, E6.GND@3, GEO5.1, J31.1, J32.1, J32.8, J32.10, J33.GND, J33.GND2, J34.1, J35.6, J36.9, PPS5.1, PWR5.1, R125.1, R126.1, R132.1, RTK5.1, SPI5.2, U26.2, U27.G1, U27.G2, U27.G3, U27.G4, U27.G5, U27.G6, U27.G7, U27.G8, U27.G9, U27.G10, U27.G11, U27.G12, U27.G13, U27.G14, U27.G15, U27.G16, U27.G17, U27.G18, U27.G19, U27.G20, U27.G21, U27.G22, U27.G23, U27.G24, U27.G25, U27.G26, U27.G27, U27.G28, U27.G29, U27.G30, U27.G31, U27.G32, U27.G33, U27.G34, U27.G35, U27.G36, U27.G37, U27.G38, U27.G39, U27.G40, U27.G41, U27.G42, U27.G43, U27.G44, U27.G45, U27.G46, U27.G47, U27.G48, U27.P1, U27.P3, U27.P12, U27.P14, U27.P32, U27.P37, U27.P41, U27.P48, U28.2, U28.3, U28.5, U29.P3, U30.P3
INT: J6.2, R8.P4
INT1: J12.2, R46.P4
INT2: J18.2, R70.P4
INT3: J24.2, R94.P4
INT4: J30.2, R118.P4
INT5: J36.2, R142.P4
unnamed: I2C.1, R23.2
unnamed: D8.C, R24.2
unnamed: I2C.3, R16.2
unnamed: D4.C, R17.2
unnamed: C8.1, FB1.2, R13.1
unnamed: D3.3, J2.A6, J2.B6
unnamed: D3.1, J2.A7, J2.B7
unnamed: PWR.2, R17.1
unnamed: D3.6, R21.1
unnamed: D3.4, R22.1
unnamed: R8.P7, U2.P49
unnamed: R8.P5, U2.P51
unnamed: D10.C, R27.2
unnamed: J2.B5, R14.2
unnamed: J2.A5, R15.2
unnamed: R9.P6, U2.P44
unnamed: R9.P5, U2.P45
unnamed: R8.P8, U2.P46
unnamed: R9.P8, U2.P42
unnamed: R9.P7, U2.P43
unnamed: R10.P1, U2.P27
unnamed: R19.1, RTK.2
unnamed: PPS.2, R18.1
unnamed: D5.C, R18.2
unnamed: D6.C, R19.2
unnamed: R10.P2, U2.P26
unnamed: R11.P2, U2.P19
unnamed: R11.P1, U2.P20
unnamed: R12.1, U2.P53
unnamed: R8.P6, U2.P50
unnamed: R10.P4, U2.P22
unnamed: R10.P3, U2.P23
unnamed: GEO.2, R20.1
unnamed: D7.C, R20.2
unnamed: C4.1, D2.3, R2.2, R6.1
unnamed: I2C1.1, R25.2
unnamed: C3.1, D1.3, R1.2, R5.1
unnamed: I2C1.3, R26.2
unnamed: J9.B5, R29.2
unnamed: J9.A5, R30.2
unnamed: R34.1, RTK1.2
unnamed: PPS1.2, R33.1
unnamed: D13.C, R33.2
unnamed: D14.C, R34.2
unnamed: D11.C, R28.2
unnamed: PWR1.2, R28.1
unnamed: C11.1, FB2.2, R35.1
unnamed: D12.3, J9.A6, J9.B6
unnamed: D12.1, J9.A7, J9.B7
unnamed: D12.6, R31.1
unnamed: D12.4, R32.1
unnamed: R46.P7, U7.P49
unnamed: R46.P5, U7.P51
unnamed: R45.P6, U7.P44
unnamed: R45.P5, U7.P45
unnamed: R46.P8, U7.P46
unnamed: R45.P8, U7.P42
unnamed: R45.P7, U7.P43
unnamed: R47.P1, U7.P27
unnamed: R47.P2, U7.P26
unnamed: R48.P2, U7.P19
unnamed: R48.P1, U7.P20
unnamed: R37.1, U7.P53
unnamed: R46.P6, U7.P50
unnamed: R47.P4, U7.P22
unnamed: R47.P3, U7.P23
unnamed: GEO1.2, R38.1
unnamed: D15.C, R38.2
unnamed: C16.1, D16.3, R39.2, R40.1
unnamed: C15.1, D17.3, R41.2, R42.1
unnamed: D19.C, R51.2
unnamed: I2C2.1, R49.2
unnamed: I2C2.3, R50.2
unnamed: J15.B5, R53.2
unnamed: J15.A5, R54.2
unnamed: R58.1, RTK2.2
unnamed: PPS2.2, R57.1
unnamed: D22.C, R57.2
unnamed: D23.C, R58.2
unnamed: D20.C, R52.2
unnamed: PWR2.2, R52.1
unnamed: C21.1, FB3.2, R59.1
unnamed: D21.3, J15.A6, J15.B6
unnamed: D21.1, J15.A7, J15.B7
unnamed: D21.6, R55.1
unnamed: D21.4, R56.1
unnamed: R70.P7, U12.P49
unnamed: R70.P5, U12.P51
unnamed: R69.P6, U12.P44
unnamed: R69.P5, U12.P45
unnamed: R70.P8, U12.P46
unnamed: R69.P8, U12.P42
unnamed: R69.P7, U12.P43
unnamed: R71.P1, U12.P27
unnamed: R71.P2, U12.P26
unnamed: R72.P2, U12.P19
unnamed: R72.P1, U12.P20
unnamed: R61.1, U12.P53
unnamed: R70.P6, U12.P50
unnamed: R71.P4, U12.P22
unnamed: R71.P3, U12.P23
unnamed: GEO2.2, R62.1
unnamed: D24.C, R62.2
unnamed: C26.1, D25.3, R63.2, R64.1
unnamed: C25.1, D26.3, R65.2, R66.1
unnamed: D28.C, R75.2
unnamed: I2C3.1, R73.2
unnamed: I2C3.3, R74.2
unnamed: J21.B5, R77.2
unnamed: J21.A5, R78.2
unnamed: R82.1, RTK3.2
unnamed: PPS3.2, R81.1
unnamed: D31.C, R81.2
unnamed: D32.C, R82.2
unnamed: D29.C, R76.2
unnamed: PWR3.2, R76.1
unnamed: C31.1, FB4.2, R83.1
unnamed: D30.3, J21.A6, J21.B6
unnamed: D30.1, J21.A7, J21.B7
unnamed: D30.6, R79.1
unnamed: D30.4, R80.1
unnamed: R94.P7, U17.P49
unnamed: R94.P5, U17.P51
unnamed: R93.P6, U17.P44
unnamed: R93.P5, U17.P45
unnamed: R94.P8, U17.P46
unnamed: R93.P8, U17.P42
unnamed: R93.P7, U17.P43
unnamed: R95.P1, U17.P27
unnamed: R95.P2, U17.P26
unnamed: R96.P2, U17.P19
unnamed: R96.P1, U17.P20
unnamed: R85.1, U17.P53
unnamed: R94.P6, U17.P50
unnamed: R95.P4, U17.P22
unnamed: R95.P3, U17.P23
unnamed: GEO3.2, R86.1
unnamed: D33.C, R86.2
unnamed: C36.1, D34.3, R87.2, R88.1
unnamed: C35.1, D35.3, R89.2, R90.1
unnamed: D37.C, R99.2
unnamed: I2C4.1, R97.2
unnamed: I2C4.3, R98.2
unnamed: J27.B5, R101.2
unnamed: J27.A5, R102.2
unnamed: R106.1, RTK4.2
unnamed: PPS4.2, R105.1
unnamed: D40.C, R105.2
unnamed: D41.C, R106.2
unnamed: D38.C, R100.2
unnamed: PWR4.2, R100.1
unnamed: C41.1, FB5.2, R107.1
unnamed: D39.3, J27.A6, J27.B6
unnamed: D39.1, J27.A7, J27.B7
unnamed: D39.6, R103.1
unnamed: D39.4, R104.1
unnamed: R118.P7, U22.P49
unnamed: R118.P5, U22.P51
unnamed: R117.P6, U22.P44
unnamed: R117.P5, U22.P45
unnamed: R118.P8, U22.P46
unnamed: R117.P8, U22.P42
unnamed: R117.P7, U22.P43
unnamed: R119.P1, U22.P27
unnamed: R119.P2, U22.P26
unnamed: R120.P2, U22.P19
unnamed: R120.P1, U22.P20
unnamed: R109.1, U22.P53
unnamed: R118.P6, U22.P50
unnamed: R119.P4, U22.P22
unnamed: R119.P3, U22.P23
unnamed: GEO4.2, R110.1
unnamed: D42.C, R110.2
unnamed: C46.1, D43.3, R111.2, R112.1
unnamed: C45.1, D44.3, R113.2, R114.1
unnamed: D46.C, R123.2
unnamed: I2C5.1, R121.2
unnamed: I2C5.3, R122.2
unnamed: J33.B5, R125.2
unnamed: J33.A5, R126.2
unnamed: R130.1, RTK5.2
unnamed: PPS5.2, R129.1
unnamed: D49.C, R129.2
unnamed: D50.C, R130.2
unnamed: D47.C, R124.2
unnamed: PWR5.2, R124.1
unnamed: C51.1, FB6.2, R131.1
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

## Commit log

2021-09-27 Initial Commit - fully routed and silked board
    [SparkFun_GPS_ZED-F9K.brd, SparkFun_GPS_ZED-F9K.sch]
2021-09-27 Updates libraries, replaces F9R with F9K, fixes some text in schematic, deletes blank sheets in schematic
    [SparkFun_GPS_ZED-F9K.brd, SparkFun_GPS_ZED-F9K.sch]
2021-09-27 Updates script being used
    [SparkFun_GPS_ZED-F9K.brd, SparkFun_GPS_ZED-F9K.sch]
2021-09-28 Moves traces for better ground pour and to reduce cross talk
    * Replaces all capacitors with smaller footprint
    * Replaces 2.2K resistors with 4.7K resistors
    [SparkFun_GPS_ZED-F9K.brd, SparkFun_GPS_ZED-F9K.sch]
2021-09-28 Adds some leftover adjustments from the last commit
    [SparkFun_GPS_ZED-F9K.brd, SparkFun_GPS_ZED-F9K.sch]
2021-09-29 Flips FTDI header, adds testpoint for VBAT, fixes dimension line width
    [SparkFun_GPS_ZED-F9K.brd, SparkFun_GPS_ZED-F9K.sch]
2021-09-29 Changes name of I2C jumper to I2C, it was previously JP6
    [SparkFun_GPS_ZED-F9K.brd, SparkFun_GPS_ZED-F9K.sch]
2021-10-01 Small changes
    [SparkFun_GPS_ZED-F9K.brd, SparkFun_GPS_ZED-F9K.sch]
2021-10-01 Fixes TXO/COPI silk to read TXO/CIPO
    [SparkFun_GPS_ZED-F9K.brd]
2021-10-01 Re-panelizes after silk change
    [SparkFun_GPS_ZED-F9K-Panel.brd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]
2021-10-04 Adds new panel from branch
    [SparkFun_GPS_ZED-F9K-Panel.brd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]
2021-11-16 Adds PROD-ID to optoisolator
    [SparkFun_GPS_ZED-F9K.brd, SparkFun_GPS_ZED-F9K.sch]

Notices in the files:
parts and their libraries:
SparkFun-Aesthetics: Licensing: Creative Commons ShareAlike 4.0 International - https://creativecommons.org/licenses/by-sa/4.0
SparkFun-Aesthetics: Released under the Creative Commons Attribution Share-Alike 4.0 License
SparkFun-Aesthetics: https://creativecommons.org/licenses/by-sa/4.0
